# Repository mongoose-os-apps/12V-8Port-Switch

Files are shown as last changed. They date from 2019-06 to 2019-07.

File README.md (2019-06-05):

# ESP8266 based 12V switch

This is a project that uses an ESP8266 to drive 8x MOSFET power ports, rated at 2A each. It incorporates a GPIO buffer (based on [MCP23008](docs/mcp23008.pdf)) to allow the MCU to reboot without changing the port status, and a current sensor (based on [INA219](docs/ina219.pdf)) to measure total current through the device.

## Hardware

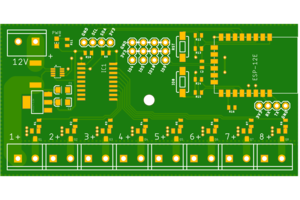
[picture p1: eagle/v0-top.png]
PCB


The schematic and board layout are in the [eagle/](eagle/) directory. You can order this board from [Oshpark](https://oshpark.com/shared_projects/42dmo9fg).

Logical components in the hardware are:

*   An LDO that steps down 12V input to 3.3V, with power LED
*   An INA219 on I2C that senses current using a 0.01 Ohm shunt resistor (32A max in 80mA steps)
*   An MCP23008 8-port GPIO expander on I2C
*   8 output ports, driven by IRLML6244 mosfets (3A max per channel)
*   An ESP8266-12E which drives the current sensor and GPIO expander over I2C
    *    RST and GPIO0 are provided via pushbuttons
*   Headers:
    *    I2C breakout for additional sensor(s)
    *    4x GPIO breakouts (GPIO: 4, 5, 9, 10)
    *    Serial access to flash the ESP8266

### BOM

Bill of materials with components and sizes:

*   AM1117-3.3V
*   C1, C2: 10uF Tantalum (3216)
*   C3: 470pF ceramic (0805)
*   IC1: MCP23008 (SO18W)
*   IO0/RST: momentary switch (6mm x 3.5mm)
*   J1-J9: screw terminal (0.2" pitch)
*   J10,J11: 4-pin standard header (0.1" pitch)
*   J12-15: 3-pin standard header (0.1" pitch)
*   MDL1: ESP8266-ESP12E
*   PWR: Green LED (0805)
*   Q1-Q8: IRLML6244 (SOT23)
*   R1-R8: 1kOhm (0805)
*   R9-R10, R12-16: 10kOhm (0805)
*   R11: 330Ohm (0805)
*   R17: 0.01Ohm Shunt (2515)
*   U1: INA219 (SOT23-8)

## Software

We use drivers for [INA219](https://github.com/mongoose-os-libs/ina219-i2c/) and [MCP23008](https://github.com/mongoose-os-libs/mcp23xxx) which are readily available for Mongoose OS. For telemetry export, we use [Prometheus](https://github.com/mongoose-os-libs/prometheus-metrics) to export metrics including standard telemetry from the ESP8266 as well as custom metrics such as port state, current and voltage.

Using the Mongoose OS [RPC Subsystem](https://github.com/mongoose-os-libs/rpc-common), we expose a simple control surface to query the ports, switch them on/off or toggle them.

By default, HTTP endpoints are provided for metrics and RPCs, which can be a security hazard. For non-trusted wifi environments, we allow allow the device to close all serving ports and service RPCs via [Pubsub](https://github.com/mongoose-os-libs/mqtt) using TLS connections to a remote [Mosquitto](https://mosquitto.org/) endpoint. Metrics can be pushed via POST requests to a Prometheus [pushgateway](https://github.com/prometheus/pushgateway).

Firmware updates can be performed [over-the-air](https://github.com/mongoose-os-libs/ota-http-client), using both HTTP as well as MQTT transport.

### API

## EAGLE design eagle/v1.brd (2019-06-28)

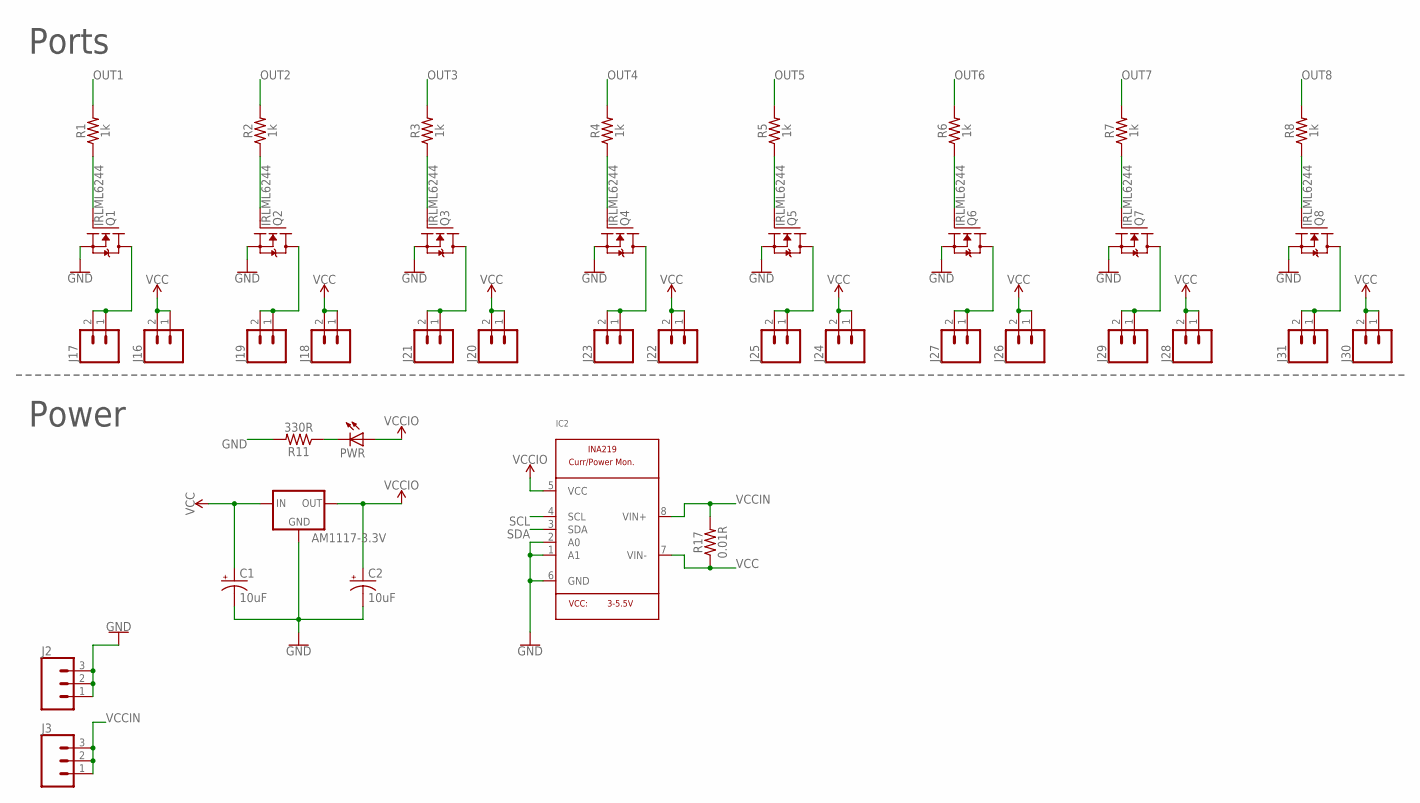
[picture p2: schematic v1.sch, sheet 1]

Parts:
AM1117-3.3V: V_REG_LD1117VXXLD1117-SMD; SOT223
C1, C2: 10uF; EIA3216
IC2: INA219SOIC8; SO08
J2, J3: CONN_03LONGPADS; 1X03_LONGPADS
J16, J17, J18, J19, J20, J21, J22, J23, J24, J25, J26, J27, J28, J29, J30, J31: CONN_02; 1X02
PWR: LEDCHIP-LED0805; CHIP-LED0805
Q1, Q2, Q3, Q4, Q5, Q6, Q7, Q8: IRLML6244; SOT23
R1, R2, R3, R4, R5, R6, R7, R8: 1k; 0805
R11: 330R; 0805
R17: 0.01R; 2512

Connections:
GND: AM1117-3.3V.1 (GND), C1.C (-), C2.C (-), IC2.1 (A1), IC2.2 (A0), IC2.6 (GND), J2.1, J2.2, J2.3, Q1.2 (S), Q2.2 (S), Q3.2 (S), Q4.2 (S), Q5.2 (S), Q6.2 (S), Q7.2 (S), Q8.2 (S), R11.2; also elsewhere on the board
unnamed: J23.1, J23.2, Q4.3 (D)
unnamed: J25.1, J25.2, Q5.3 (D)
unnamed: J27.1, J27.2, Q6.3 (D)
unnamed: Q1.1 (G), R1.1
unnamed: Q2.1 (G), R2.1
unnamed: Q3.1 (G), R3.1
unnamed: Q4.1 (G), R4.1
unnamed: Q5.1 (G), R5.1
unnamed: Q6.1 (G), R6.1
unnamed: Q7.1 (G), R7.1
unnamed: Q8.1 (G), R8.1
unnamed: PWR.C, R11.1
unnamed: J17.1, J17.2, Q1.3 (D)
unnamed: J19.1, J19.2, Q2.3 (D)
unnamed: J21.1, J21.2, Q3.3 (D)
unnamed: J29.1, J29.2, Q7.3 (D)
unnamed: J31.1, J31.2, Q8.3 (D)
OUT1: R1.2; also elsewhere on the board
OUT2: R2.2; also elsewhere on the board
OUT3: R3.2; also elsewhere on the board
OUT4: R4.2; also elsewhere on the board
OUT5: R5.2; also elsewhere on the board
OUT6: R6.2; also elsewhere on the board
OUT7: R7.2; also elsewhere on the board
OUT8: R8.2; also elsewhere on the board
SCL: IC2.4 (SCL); also elsewhere on the board
SDA: IC2.3 (SDA); also elsewhere on the board
VCC: AM1117-3.3V.3 (IN), C1.A (+), IC2.7 (VIN-), J16.1, J16.2, J18.1, J18.2, J20.1, J20.2, J22.1, J22.2, J24.1, J24.2, J26.1, J26.2, J28.1, J28.2, J30.1, J30.2, R17.P$1 (1)
VCCIN: IC2.8 (VIN+), J3.1, J3.2, J3.3, R17.P$2 (2)
VCCIO: AM1117-3.3V.2 (OUT), C2.A (+), IC2.5 (VCC), PWR.A; also elsewhere on the board

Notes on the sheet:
Power
Ports

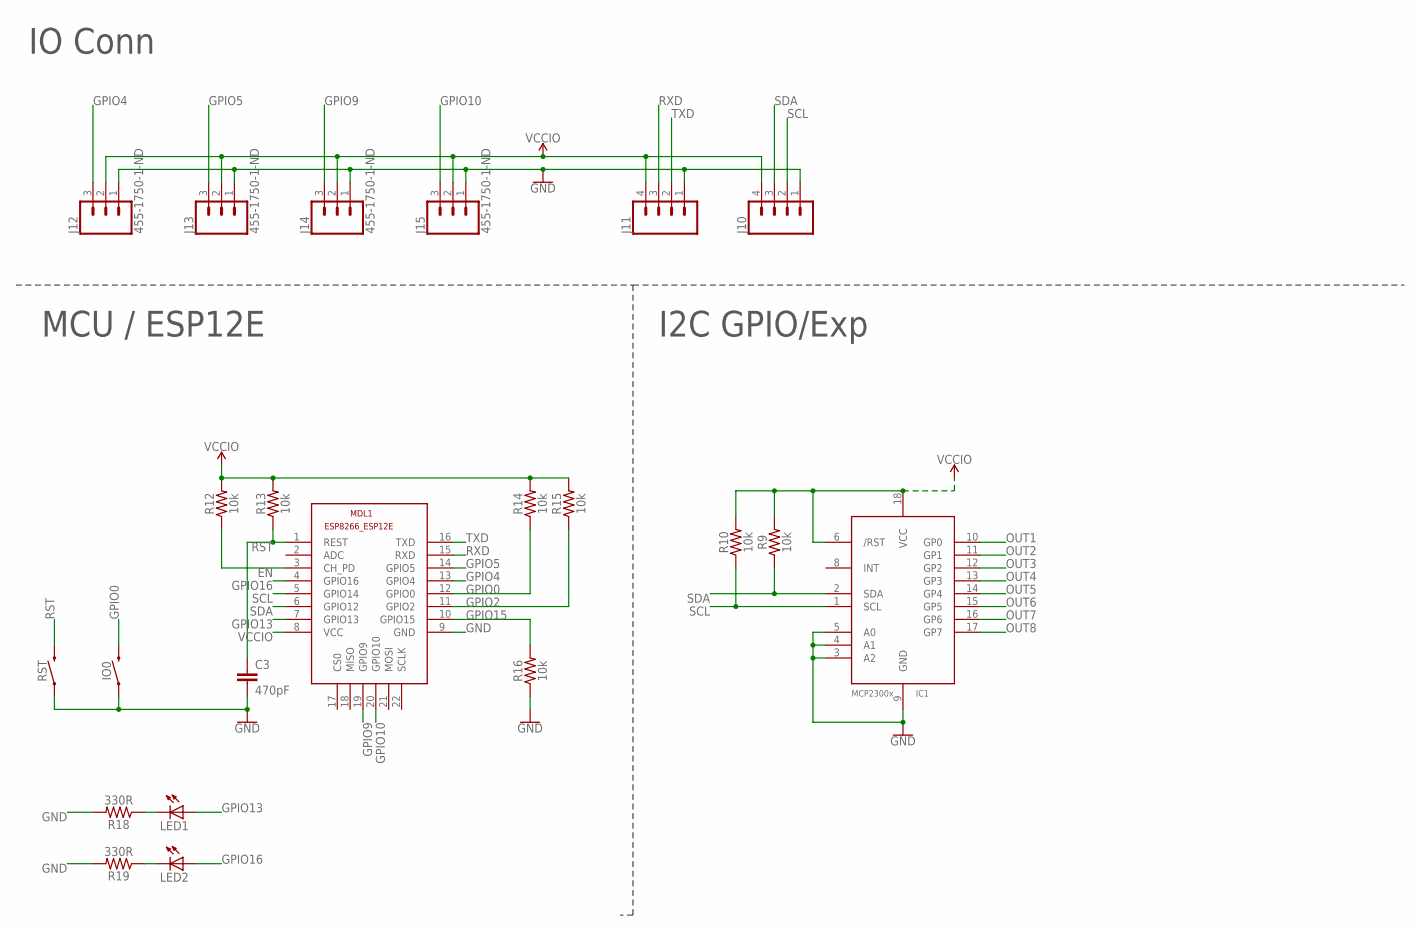
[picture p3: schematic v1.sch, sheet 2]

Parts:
C3: 470pF; 0805
IC1: MCP23008/SO; SO18W
IO0: MOMENTARY-SWITCH-SPST-SMD-6.0X3.5MM; TACTILE_SWITCH_SMD_6.0X3.5MM
J10, J11: CONN_04PTH; 1X04
J12, J13, J14, J15: 455-1750-1-ND; 1X03
LED1, LED2: LEDCHIP-LED0805; CHIP-LED0805
MDL1: ESP8266-12EESP8266-ESP12E; ESP8266-ESP12E
R9, R10, R12, R13, R14, R15, R16: 10k; 0805
R18, R19: 330R; 0805
RST: MOMENTARY-SWITCH-SPST-SMD-6.0X3.5MM; TACTILE_SWITCH_SMD_6.0X3.5MM

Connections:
EN: MDL1.3 (CH_PD), R12.1
GND: C3.2, IC1.3 (A2), IC1.4 (A1), IC1.5 (A0), IC1.9 (GND), IO0.1, J10.1, J11.1, J12.1, J13.1, J14.1, J15.1, MDL1.9 (GND), R16.1, R18.2, R19.2, RST.1; also elsewhere on the board
GPIO0: IO0.2, MDL1.12 (GPIO0), R14.1
GPIO2: MDL1.11 (GPIO2), R15.1
GPIO4: J12.3, MDL1.13 (GPIO4)
GPIO5: J13.3, MDL1.14 (GPIO5)
GPIO9: J14.3, MDL1.19 (GPIO9)
GPIO10: J15.3, MDL1.20 (GPIO10)
GPIO13: LED1.A, MDL1.7 (GPIO13)
GPIO15: MDL1.10 (GPIO15), R16.2
GPIO16: LED2.A, MDL1.4 (GPIO16)
unnamed: LED1.C, R18.1
unnamed: LED2.C, R19.1
OUT1: IC1.10 (GP0); also elsewhere on the board
OUT2: IC1.11 (GP1); also elsewhere on the board
OUT3: IC1.12 (GP2); also elsewhere on the board
OUT4: IC1.13 (GP3); also elsewhere on the board
OUT5: IC1.14 (GP4); also elsewhere on the board
OUT6: IC1.15 (GP5); also elsewhere on the board
OUT7: IC1.16 (GP6); also elsewhere on the board
OUT8: IC1.17 (GP7); also elsewhere on the board
RST: C3.1, MDL1.1 (REST), R13.1, RST.2
RXD: J11.3, MDL1.15 (RXD)
SCL: IC1.1 (SCL), J10.2, MDL1.5 (GPIO14), R10.1; also elsewhere on the board
SDA: IC1.2 (SDA), J10.3, MDL1.6 (GPIO12), R9.1; also elsewhere on the board
TXD: J11.2, MDL1.16 (TXD)
VCCIO: IC1.6 (/RST), IC1.18 (VCC), J10.4, J11.4, J12.2, J13.2, J14.2, J15.2, MDL1.8 (VCC), R9.2, R10.2, R12.2, R13.2, R14.2, R15.2; also elsewhere on the board

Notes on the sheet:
I2C GPIO/Exp
IO Conn
MCU / ESP12E

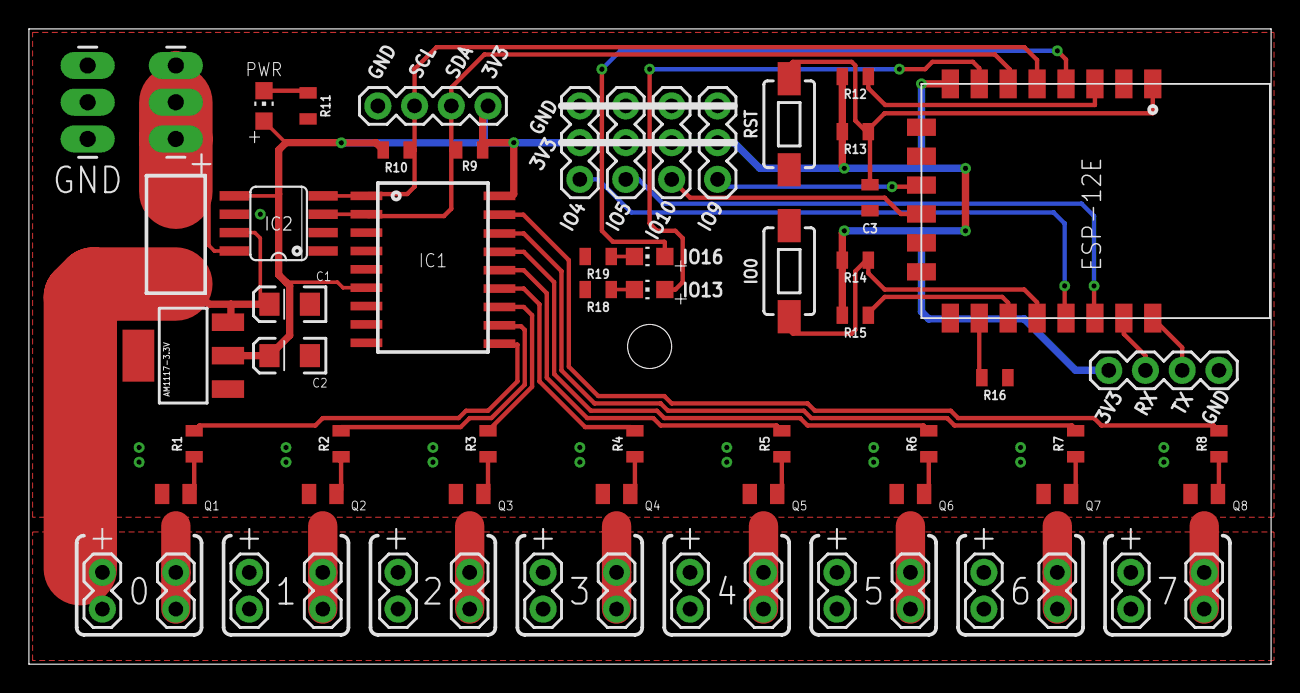
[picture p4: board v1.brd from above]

Board: 2 copper layers, 85.9 x 43.9 mm, 63 parts (0 on the bottom side), 46 nets.

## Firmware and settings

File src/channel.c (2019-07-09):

#include "channel.h"
#include "mgos_config.h"
#include "mgos_mcp23xxx.h"

static struct mgos_mcp23xxx *s_gpio = NULL;

int channel_get_total(void) {
  return 8;
}

bool channel_is_valid(int channel) {
  if (channel < 0) return false;
  if (channel >= channel_get_total()) return false;
  return true;
}

bool channel_get(int channel, bool *state) {
  if (!state) return false;
  if (!channel_is_valid(channel)) return false;
  *state = mgos_mcp23xxx_gpio_read(s_gpio, channel);
  return true;
}

bool channel_set(int channel, bool state) {
  if (!channel_is_valid(channel)) return false;
  mgos_mcp23xxx_gpio_write(s_gpio, channel, state);
  return true;
}

bool channel_toggle(int channel) {
  bool state;

  if (!channel_is_valid(channel)) return false;
  if (!channel_get(channel, &state)) return false;

  return channel_set(channel, !state);
}

static void channel_status(void *arg) {
  mgos_mcp23xxx_print_state(s_gpio);
  (void) arg;
}

bool channel_init(void) {
  int i;

  if (!(s_gpio = mgos_mcp23008_create(
            mgos_i2c_get_global(), mgos_sys_config_get_mcp23xxx_i2caddr(),
            mgos_sys_config_get_mcp23xxx_int_gpio()))) {
    LOG(LL_ERROR, ("Could not create MCP23008"));
    return false;
  }

  for (i = 0; i < 8; i++)
    mgos_mcp23xxx_gpio_set_mode(s_gpio, i, MGOS_GPIO_MODE_OUTPUT);

  mgos_set_timer(5000, true, channel_status, NULL);

  return true;
}

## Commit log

2019-06-04 Add Eagle schematic
    [v0.brd, v0.sch]
2019-06-05 Add BOM
2019-06-05 Fix LED polarity - caught by my dad :)
    [v0.brd, v0.sch]
2019-06-22 Add a 5s timer to print channel state to serial
2019-06-28 v1 of the board -- added 2 LEDs (GPIO13, GPIO16), and swapped out INA219 from SOT23-8 to SOIC-8, and swapped out screw terminals for tabs
    [v1.brd, v1.sch]
2019-07-09 Add INA219 current sensor, write to serial every second, add prometheus metrics exports

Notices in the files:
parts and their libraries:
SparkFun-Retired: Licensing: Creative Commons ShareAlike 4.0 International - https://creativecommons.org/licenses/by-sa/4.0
